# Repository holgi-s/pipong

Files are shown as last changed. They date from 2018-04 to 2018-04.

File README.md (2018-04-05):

# Raspberry Pi Powered Pong Game.

## Hardware

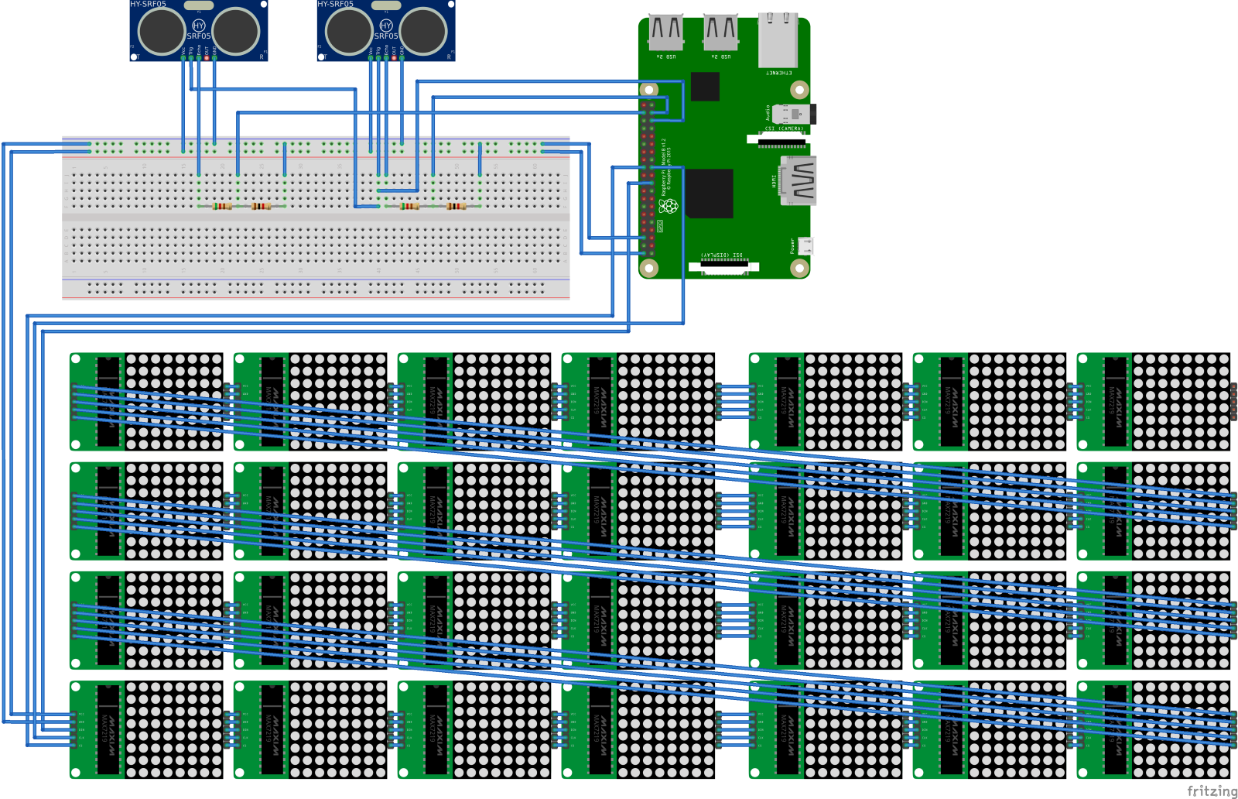
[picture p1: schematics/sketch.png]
sketch Full sketch


### Input
**2 x HC-SR 04 ultra sonic range sensor**

Both range sensors share one trigger signal from the PI.  
The 5V echo pins from the sensors are connected back to the Pi via voltage dividers. 

### Display
**28 x MAX7219 based 8x8 LED panels**

The LED panels are controlled by a SPI like interface.  
All panels are daisy-chained together. So the complete display can be updated with 8 consecutive SPI bus writes.  
Each write will update 1 row off all the 28 connected panels. The LED data is written by using the SPI bus, 
except that the internal SPI_CS signal of the bus will not be used and instead a custom CS signal will load 
the data into the MAX7219 after the full transfer for one row of all panels is complete.

## Software

Hardware interface is realised by using pigpio library.

    sudo apt-get update
    sudo apt-get install pigpio

See http://abyz.me.uk/rpi/pigpio/index.html for more infos about pigpio.

**RangeController**  

A background thread with an endless loop is sending a 10µs pulse on the trigger pin every 60ms.  
(Sending in a faster interval led to unreliable results)

Two callback are registered for both echo pins measuring the echo pulse length. 
The pulse length multiplied by the speed of sound and divided by 2 (for the round trip) 
will give us the measured distance for each sensor. The pigpio library helps a lot here, because it 
timestamps all changes on the GPIOs.

**LedController**  

The LedController handles the communication with the LED panels. Basically it will transfer the bitmasks for 
all led panels via SPI. For one panel it will be a regular data transfer via SPI, but since we daisy chained all the 
panels, we need to customise the protocol. We can load the complete chain of LED panels with one SPI transfer if
we manually toggle the CS pin. So we pull down the CS, transfer data for all panels and raise CS again to load the data
into the LED. 

**FrameBuffer**  

The FrameBuffer keeps track of the display data. The internal memory layout is matching hte LED panel chain. 
In addition it provides logical access via "screen" coordinates. 

**Text/BinaryDisplay**  

Helper classes to write text or draw lines onto the FrameBuffer

**Game**  

Pong! A field, two tennis rackets and a ball.

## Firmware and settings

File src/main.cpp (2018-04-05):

#include "PiGpio.h"
#include "LedController2.h"
#include "RangeController.h"
#include "GameApp.h"

static bool _quit_app = false;

#include <iostream>
#include <signal.h>

void sig_handler(int  s){
    std::cout << std::endl << "Ctrl-C signal caught! " << std::endl << "Quiting the game..." << std::endl;
    _quit_app = true;
}

int main() {

    std::cout << "Starting the game..." << std::endl;

    signal (SIGINT, sig_handler);
    PiGpio gpio;
    LedController2 led(gpio.get_handle(), 28);
    RangeController range(gpio.get_handle());

    GameApp app(led, range, _quit_app);
    app.play_loop();

    std::cout << "Bye!" << std::endl;

    return 0;
}

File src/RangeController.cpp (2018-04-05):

//
// Created by Holger on 17.03.2018.
//

#include "RangeController.h"

#include "sleep.h"
#include "pigpio_interface.h"

#include <iostream>
#include <time.h>
#include <cmath>
#include <numeric>
#include <algorithm>

#define MAX_DISTANCE_ENTRIES 2

#define DIST_TRIGGER_1   19
#define DIST_ECHO_1      26
#define DIST_ECHO_2      20

void fn_echo_callback(int pi, unsigned gpio, unsigned level, uint32_t tick, void* p_this);
void * fn_trigger_thread(void * p_this);

RangeController::RangeController(int pigpioHandle) {

    //std::cout << "RangeController! "  << std::endl;

    _fd = pigpioHandle;

    int err = 0;

    set_mode(_fd, DIST_TRIGGER_1, PI_OUTPUT);
    gpio_write(_fd, DIST_TRIGGER_1, 0);

    set_pull_up_down(_fd, DIST_ECHO_1, PI_PUD_OFF);
    set_mode(_fd, DIST_ECHO_1, PI_INPUT);

    _callback_id1 = callback_ex(_fd, DIST_ECHO_1, EITHER_EDGE, fn_echo_callback, this);
    //std::cout << "callback: " << _callback_id1 << std::endl;

    set_pull_up_down(_fd, DIST_ECHO_2, PI_PUD_OFF);
    set_mode(_fd, DIST_ECHO_2, PI_INPUT);

    _callback_id2 = callback_ex(_fd, DIST_ECHO_2, EITHER_EDGE, fn_echo_callback, this);
    //std::cout << "callback: " << _callback_id2 << std::endl;

    for(int i=0; i<MAX_DISTANCE_ENTRIES; ++i) {
        _last_distances1.push_back(0);
        _last_distances2.push_back(0);
    }

    _quit_trigger_thread = false;
    _trigger_thread = start_thread(fn_trigger_thread, this);
}


RangeController::~RangeController() {

    //std::cout << "stopDistance: " << std::endl;

    _quit_trigger_thread = true;
    stop_thread(_trigger_thread);

    int err = callback_cancel(_callback_id1);
    //std::cout << "callback_cancel: " << err << std::endl;

    err = callback_cancel(_callback_id2);
    //std::cout << "callback_cancel: " << err << std::endl;
}

void fn_echo_callback(int pi, unsigned gpio, unsigned level, uint32_t tick, void* p_this) {
    if(p_this) {
        static_cast<RangeController*>(p_this)->echo_callback(pi, gpio, level, tick);
    }
}

void RangeController::echo_callback(int pi, unsigned gpio, unsigned level, uint32_t tick) {

   //std::cout << "echo_callback: " << level << std::endl;

    if(level==1) {
        if(gpio == DIST_ECHO_1) {
            _start_tick1 = tick;
        } else {
            _start_tick2 = tick;
        }
    } else if(level == 0){

        float distance = calc_distance(( gpio == DIST_ECHO_1 ? _start_tick1 : _start_tick2), tick);

        if( gpio == DIST_ECHO_1 ){
            if(distance > 600) {
                distance = _last_filtered_distance1.load();
            }
            _last_distances1.push_back(distance);
            _last_distances1.pop_front();
            float min = *std::min_element(_last_distances1.begin(), _last_distances1.end());
            _last_filtered_distance1.store(filter_low_pass(_last_filtered_distance1.load(), min));
        }else{
            if(distance > 600) {
                distance = _last_filtered_distance2.load();
            }
            _last_distances2.push_back(distance);
            _last_distances2.pop_front();
            float min = *std::min_element(_last_distances2.begin(), _last_distances2.end());
            _last_filtered_distance2.store(filter_low_pass(_last_filtered_distance2.load(), min));
        }
        //std::cout << "echo_callback: " << lastLevel << " mm" << std::endl;
    }

}

float RangeController::filter_low_pass(float old_value, float new_value) {
    const float scale = 0.5f;
    return (1.0f-scale) * old_value + (scale) * new_value;
}

float RangeController::calc_distance(uint32_t start_tick, uint32_t stop_tick){
    const uint32_t peak_tick = stop_tick - start_tick;
    const float peak_time = (float)peak_tick / 1000000.0f; // [µsec] -> [sec]
    const float sound_velocity = 343.2f; // [m/sec] TODO: adjust for temperature
    const float distance_meter = peak_time * sound_velocity / 2; // [m], (roundtrip -> /2)
    const float distance_mm = distance_meter * 1000;
    return distance_mm;
}

void * fn_trigger_thread(void * p_this){
    if(p_this) {
        static_cast<RangeController*>(p_this)->trigger_thread();
    }
}

void RangeController::trigger_thread(){

    //std::cout << "starting trigger_thread..."  << std::endl;

    //documentations is not quite clear it could be a 40Hz measurement cycle or more likely a 16 Hz cycle
    //using the 60ms trigger cycle works quite reliable

    while(!_quit_trigger_thread){
        trigger();
        sleep_ms(60);
    }

    //std::cout << "quit trigger_thread!"  << std::endl;
}

void RangeController::trigger() {
    gpio_trigger(_fd, DIST_TRIGGER_1, 10, 1);
}

int RangeController::lastDistance(){
    return (int)std::round(_last_filtered_distance1.load());
}

int RangeController::lastDistance2(){
    return (int)std::round(_last_filtered_distance2.load());
}

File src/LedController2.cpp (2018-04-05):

//
// Created by Holger on 12.1.2018.
//

#include "LedController2.h"
#include "pigpio_interface.h"

#include <iostream>
#include <time.h>
#include <cmath>
#include <numeric>

#define SPI_MOSI   10
#define SPI_CS1    7
#define SPI_CS0    8
#define SPI_CLK    11
#define SPI_MISO   9

#define DIST_TRIGGER_1   19
#define DIST_ECHO_1      26
#define DIST_ECHO_2      20

#define SPI_BUS_SPEED 921600


LedController2::LedController2(int pigpio_handle, int panel_count) {

    //std::cout << "LedController2! "  << std::endl;

    _fd = pigpio_handle;

    _panel_count = panel_count;

    set_mode(_fd, SPI_MOSI, PI_OUTPUT);
    set_mode(_fd, SPI_CS0, PI_OUTPUT);
    set_mode(_fd, SPI_CS1, PI_OUTPUT);
    set_mode(_fd, SPI_CLK, PI_OUTPUT);
    set_mode(_fd, SPI_MISO, PI_INPUT);

    //set channel to cs1 because we will manually toggle cs0
    unsigned spi_flags = 0;
    _spi = spi_open(_fd, 1, SPI_BUS_SPEED, spi_flags); // channel 1 -> cs1

    setTestMode(false);
    setDecodeMode(0);
    setScanLimit(7);
    setIntensity(2);
    setShutdownMode(false);

}


LedController2::~LedController2() {

    setShutdownMode(true);

    spi_close(_fd, _spi);

}

void LedController2::setDecodeMode(uint8_t mode)
{
    std::vector<uint8_t> values(_panel_count, mode);
    write(0x09, values);
}
void LedController2::setIntensity(uint8_t intensity) {
    std::vector<uint8_t> values(_panel_count, intensity);
    write(0x0a, values);
}

void LedController2::setScanLimit(uint8_t scanLimit) {
    std::vector<uint8_t> values(_panel_count, scanLimit);
    write(0x0b, values);
}
void LedController2::setShutdownMode(bool shutdown){
    std::vector<uint8_t> values(_panel_count, shutdown ? 0 : 1);
    write(0x0c, values);
}

void LedController2::setTestMode(bool test){
    std::vector<uint8_t> values(_panel_count, test ? 1: 0);
    write(0x0f, values); }


void LedController2::write(uint8_t adr, uint8_t data0, uint8_t data1, uint8_t data2, uint8_t data3) {
    write(((adr&0x0f)<<8) | data0, ((adr&0x0f)<<8) | data1, ((adr&0x0f)<<8) | data2, ((adr&0x0f)<<8) | data3);
}

void LedController2::write(uint16_t word0, uint16_t word1, uint16_t word2, uint16_t word3) {

    char buf[8];
    buf[0] = (word0 & 0xff00)  >> 8;
    buf[1] = word0 & 0xff;
    buf[2] = (word1 & 0xff00)  >> 8;
    buf[3] = word1 & 0xff;
    buf[4] = (word2 & 0xff00)  >> 8;
    buf[5] = word2 & 0xff;
    buf[6] = (word3 & 0xff00)  >> 8;
    buf[7] = word3 & 0xff;

    gpio_write(_fd, SPI_CS0, 0);
    spi_write(_fd, _spi, buf, 8);
    gpio_write(_fd, SPI_CS0, 1);
}

void LedController2::write(uint8_t adr, const std::vector<uint8_t>& data) {

    adr = adr & 0x0f;

    std::vector<char> buffer;
    buffer.reserve(data.size()*2);
    for (uint8_t b : data) {
        buffer.push_back(adr);
        buffer.push_back(b);
    }

    gpio_write(_fd, SPI_CS0, 0);
    spi_write(_fd, _spi, &buffer[0], data.size()*2);
    gpio_write(_fd, SPI_CS0, 1);
}

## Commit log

2018-04-05 added all game files
    [sketch.fzz]
2018-04-05 reorganised project structure
    [sketch.fzz]
